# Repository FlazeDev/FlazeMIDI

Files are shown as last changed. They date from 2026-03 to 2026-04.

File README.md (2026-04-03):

# FlazeMIDI

Screenshot (118)

This is a simple 25 key MIDI Controller with 3 rotary encoders. I used a Raspberry Pi Pico as the brain for this MIDI Controller.

## Bill of Materials (BOM)
|BOM for FlazeMIDI|FIELD2 |FIELD3 |FIELD4 |FIELD5 |FIELD6 |
|---|---|---|---|---|---|
|S.No |Name Of Part |Link |Price per item(W/o Shipping)|Quantity |Total Cost Of Item(W/O Shipping)|
|1 |Raspberry pi pico |https://robu.in/product/raspberry-pi-pico-with-headers/ |499.00 INR |1 |499.00 INR |
|2 |1N4148 diodes(pack of 50) |https://www.amazon.in/gp/product/B0B53NV1QC/ref=ox_sc_act_title_1?smid=A3OFZYSBUU01KL&psc=1|99.00 INR |1 |99.00 INR |
|3 |Switches(pack of 10) |https://stackskb.com/store/click-inc-hp-switch-pack-of-10-pre-order/ |180.00 INR |3 |540.00 INR |
|4 |EC11 Rotary Encoders(pack of 5)|https://stackskb.com/store/click-inc-hp-switch-pack-of-10-pre-order/ |696.00 INR |1 |696.00 INR |
|5 |Keycaps(pack of 5) |https://meckeys.com/shop/accessories/keyboard-accessories/keycaps/blank-dsa-keycaps-1u/ |95.00 INR |5 |475.00 INR |
|6 |PCB Fabrication |jlcpcb.com |976.96 INR |1 |976.96 INR |
|7 |PCB Shipping |jlcpcb.com |1,091.73 INR |1 |1,091.73 INR |
|8 |M3x4mm Heatsets |I already have it |0.00 INR |4 |0.00 INR |
|9 |M3x4mm screws |I already have it |0.00 INR |4 |0.00 INR |
| | | | | | |
| | | | | | |
| | | | | | |
| | | | | | |
| | | | | | |
| | | | | | |
| | | | |Total INR(only including  Shipping for pcb)|4,377.69 INR |
| | | | |Total USD |$48.15 |

### Total Project Cost
$48.15 without shipping. Shipping should take another $10 max.
Total Project cost: **$58**

## Schematic & PCB
Screenshot (109)
Screenshot (104)

I made the pcb in kicad

## 3d Case
Screenshot (119)

The case consists of 3 parts, the top cover, bottom cover and a stand that attaches to the bottom. Everything is connected using m3 heat set inserts and screws.
I made the case in onshape. here's the link for the onshape project:- https://cad.onshape.com/documents/0f47473beb05ba1bc00654df/w/e1cbcdd202a0a0f5e24ed7bd/e/dbeb9d6fbd234f685e1c68c6

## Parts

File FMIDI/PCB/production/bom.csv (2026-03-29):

Designator | Footprint | Quantity | Value | LCSC Part #
D1, D10, D11, D12, D13, D14, D15, D16, D17, D18, D19, D2, D20, D21, D22, D23, D24, D25, D3, D4, D5, D6, D7, D8, D9 | D_DO-35_SOD27_P7.62mm_Horizontal | 25 | ~
S1, S10, S11, S12, S13, S14, S15, S16, S17, S18, S19, S2, S20, S21, S22, S23, S24, S25, S3, S4, S5, S6, S7, S8, S9 | MX_PCB_1.00u | 25 | ~
SW1, SW2, SW3 | Encoder_EC11_MX | 3 | RotaryEncoder_Switch
U1 | Raspberry_Pi_Pico | 1 | Raspberry_Pi_Pico

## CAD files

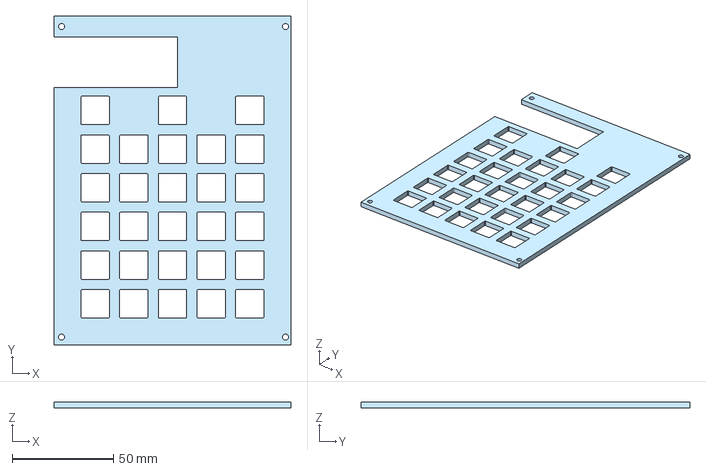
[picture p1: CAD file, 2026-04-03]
FMIDI/CAD/FMIDI_Top.step
116.8 x 162.0 x 3.00 mm

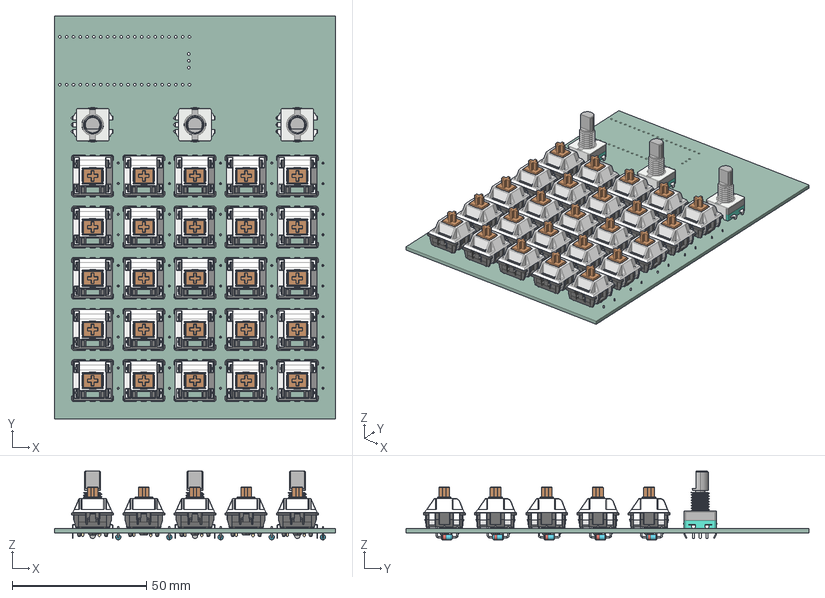
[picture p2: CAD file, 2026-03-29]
FMIDI/PCB/MIDI/MIDI.step
104.8 x 150.0 x 25.6 mm
ѽת±ძǷ x 3
SW_Cherry_MX_PCB_cp x 25
D_DO-35_SOD27_P7.62mm_Horizontal x 25
_autosave-MIDI_PCB

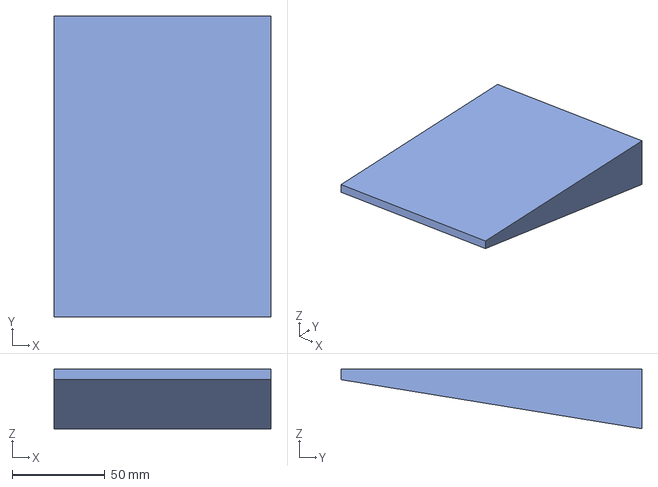
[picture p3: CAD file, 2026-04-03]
FMIDI/CAD/FMIDI_Stand.step
116.8 x 162.0 x 32.0 mm

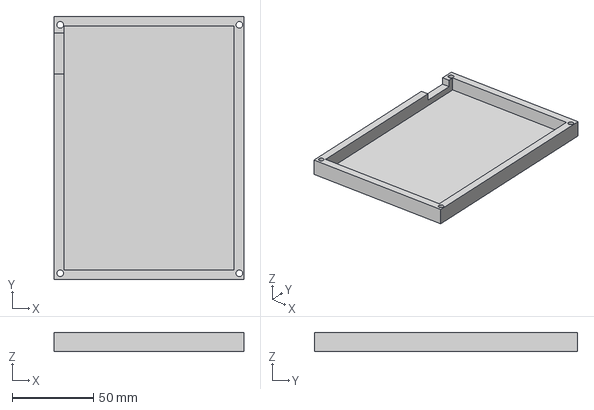
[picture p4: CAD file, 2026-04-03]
FMIDI/CAD/FMIDI_Bottom.step
116.8 x 162.0 x 12.0 mm

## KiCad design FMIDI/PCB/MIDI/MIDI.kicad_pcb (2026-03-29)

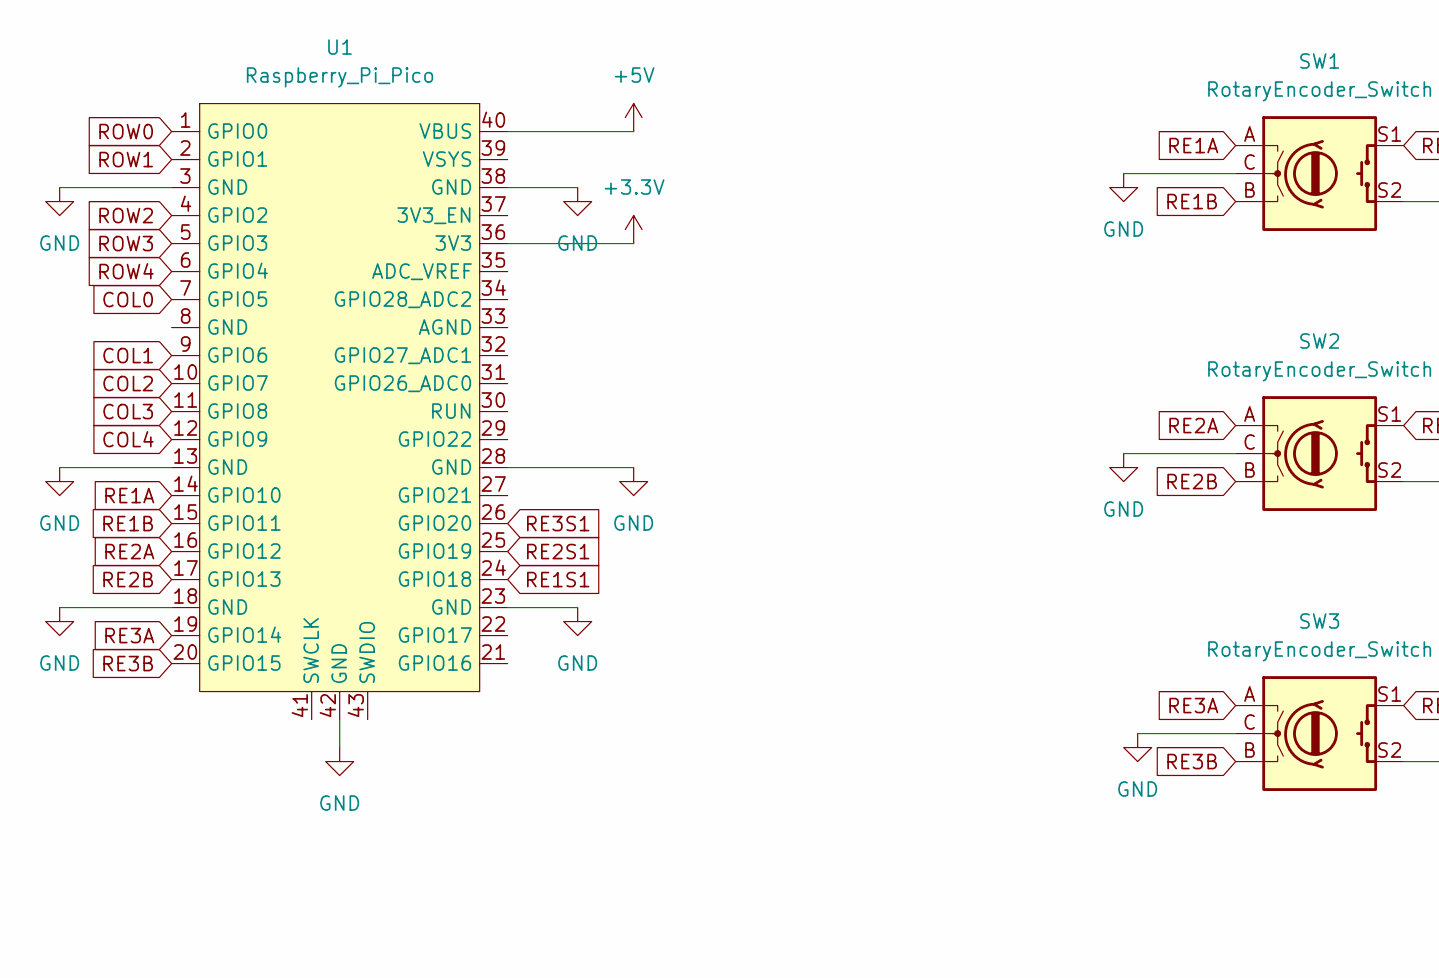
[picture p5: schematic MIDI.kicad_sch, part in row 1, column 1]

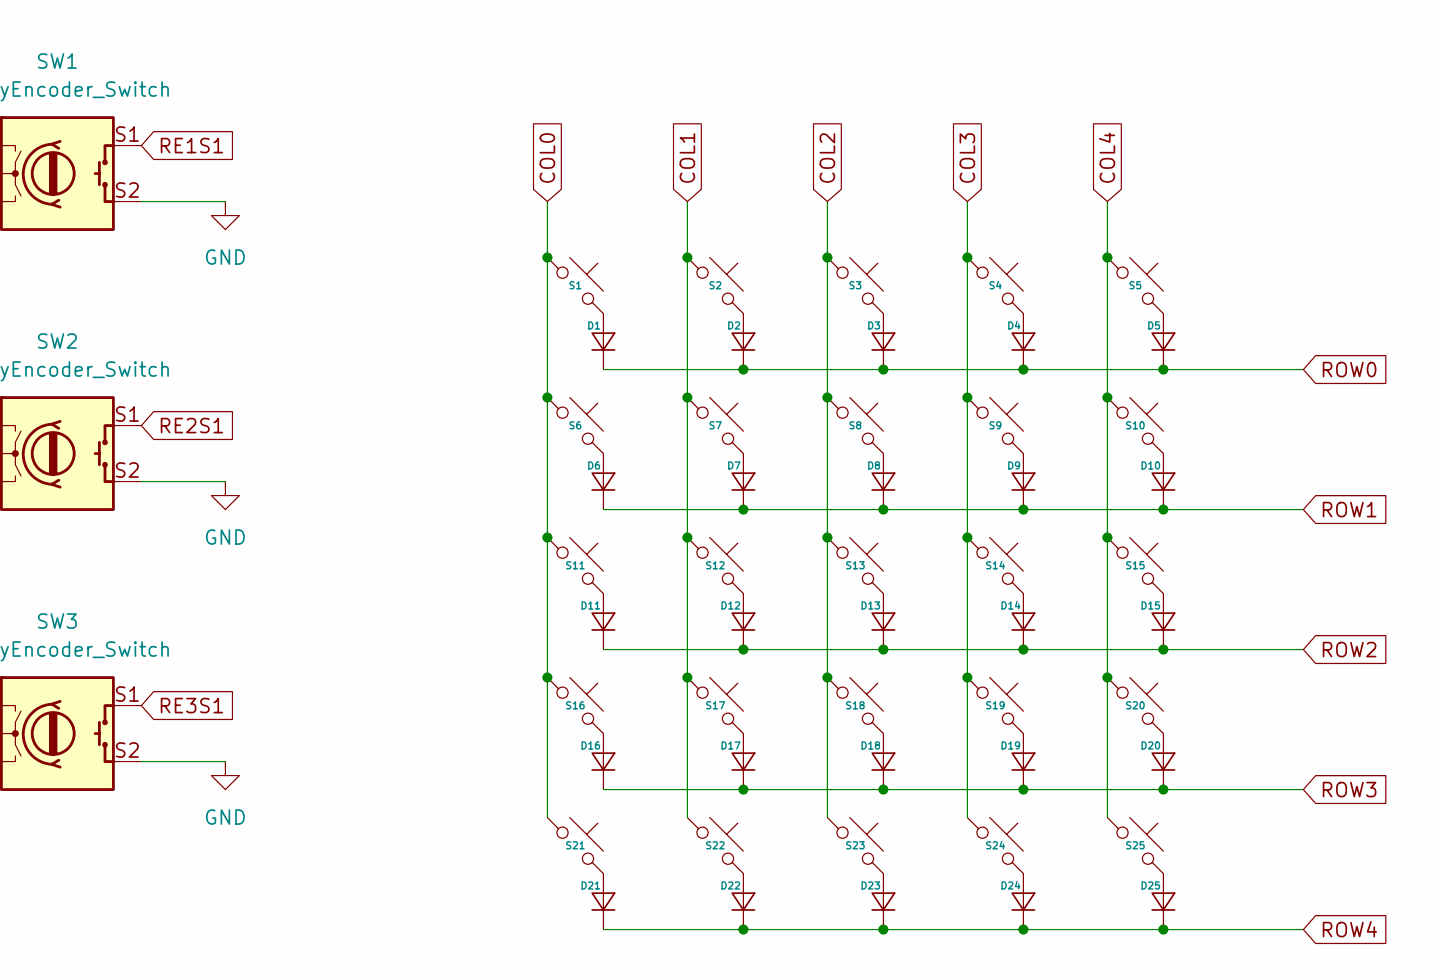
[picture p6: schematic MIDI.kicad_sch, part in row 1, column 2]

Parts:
D1, D2, D3, D4, D5, D6, D7, D8, D9, D10, D11, D12, D13, D14, D15, D16, D17, D18, D19, D20, D21, D22, D23, D24, D25: D_DO-35_SOD27_P7.62mm_Horizontal
S1, S2, S3, S4, S5, S6, S7, S8, S9, S10, S11, S12, S13, S14, S15, S16, S17, S18, S19, S20, S21, S22, S23, S24, S25: MX_PCB_1.00u
SW1, SW2, SW3: RotaryEncoder_Switch; Encoder_EC11_MX
U1: Raspberry_Pi_Pico

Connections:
+3.3V: U1.36 (3V3)
+5V: U1.40 (VBUS)
COL0: S1.1, S6.1, S11.1, S16.1, S21.1, U1.7 (GPIO5)
COL1: S2.1, S7.1, S12.1, S17.1, S22.1, U1.9 (GPIO6)
COL2: S3.1, S8.1, S13.1, S18.1, S23.1, U1.10 (GPIO7)
COL3: S4.1, S9.1, S14.1, S19.1, S24.1, U1.11 (GPIO8)
COL4: S5.1, S10.1, S15.1, S20.1, S25.1, U1.12 (GPIO9)
GND: SW1.C, SW1.S2, SW2.C, SW2.S2, SW3.C, SW3.S2, U1.3 (GND), U1.13 (GND), U1.18 (GND), U1.23 (GND), U1.28 (GND), U1.38 (GND), U1.42 (GND)
unnamed: D1.2 (A), S1.2
unnamed: D2.2 (A), S2.2
unnamed: D3.2 (A), S3.2
unnamed: D4.2 (A), S4.2
unnamed: D5.2 (A), S5.2
unnamed: D6.2 (A), S6.2
unnamed: D7.2 (A), S7.2
unnamed: D8.2 (A), S8.2
unnamed: D9.2 (A), S9.2
unnamed: D10.2 (A), S10.2
unnamed: D11.2 (A), S11.2
unnamed: D12.2 (A), S12.2
unnamed: D13.2 (A), S13.2
unnamed: D14.2 (A), S14.2
unnamed: D15.2 (A), S15.2
unnamed: D16.2 (A), S16.2
unnamed: D17.2 (A), S17.2
unnamed: D18.2 (A), S18.2
unnamed: D19.2 (A), S19.2
unnamed: D20.2 (A), S20.2
unnamed: D21.2 (A), S21.2
unnamed: D22.2 (A), S22.2
unnamed: D23.2 (A), S23.2
unnamed: D24.2 (A), S24.2
unnamed: D25.2 (A), S25.2
RE1A: SW1.A, U1.14 (GPIO10)
RE1B: SW1.B, U1.15 (GPIO11)
RE1S1: SW1.S1, U1.24 (GPIO18)
RE2A: SW2.A, U1.16 (GPIO12)
RE2B: SW2.B, U1.17 (GPIO13)
RE2S1: SW2.S1, U1.25 (GPIO19)
RE3A: SW3.A, U1.19 (GPIO14)
RE3B: SW3.B, U1.20 (GPIO15)
RE3S1: SW3.S1, U1.26 (GPIO20)
ROW0: D1.1 (K), D2.1 (K), D3.1 (K), D4.1 (K), D5.1 (K), U1.1 (GPIO0)
ROW1: D6.1 (K), D7.1 (K), D8.1 (K), D9.1 (K), D10.1 (K), U1.2 (GPIO1)
ROW2: D11.1 (K), D12.1 (K), D13.1 (K), D14.1 (K), D15.1 (K), U1.4 (GPIO2)
ROW3: D16.1 (K), D17.1 (K), D18.1 (K), D19.1 (K), D20.1 (K), U1.5 (GPIO3)
ROW4: D21.1 (K), D22.1 (K), D23.1 (K), D24.1 (K), D25.1 (K), U1.6 (GPIO4)

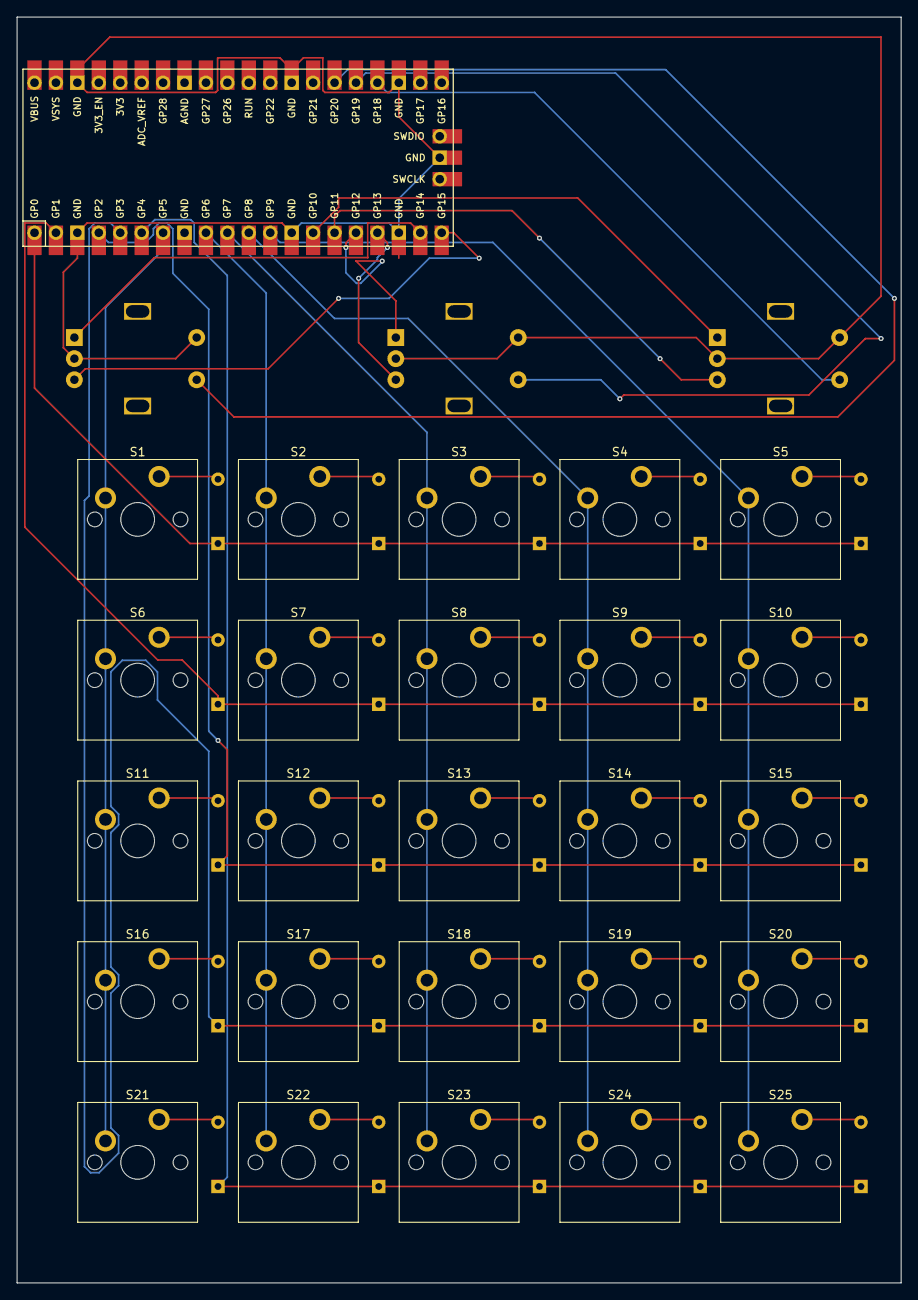
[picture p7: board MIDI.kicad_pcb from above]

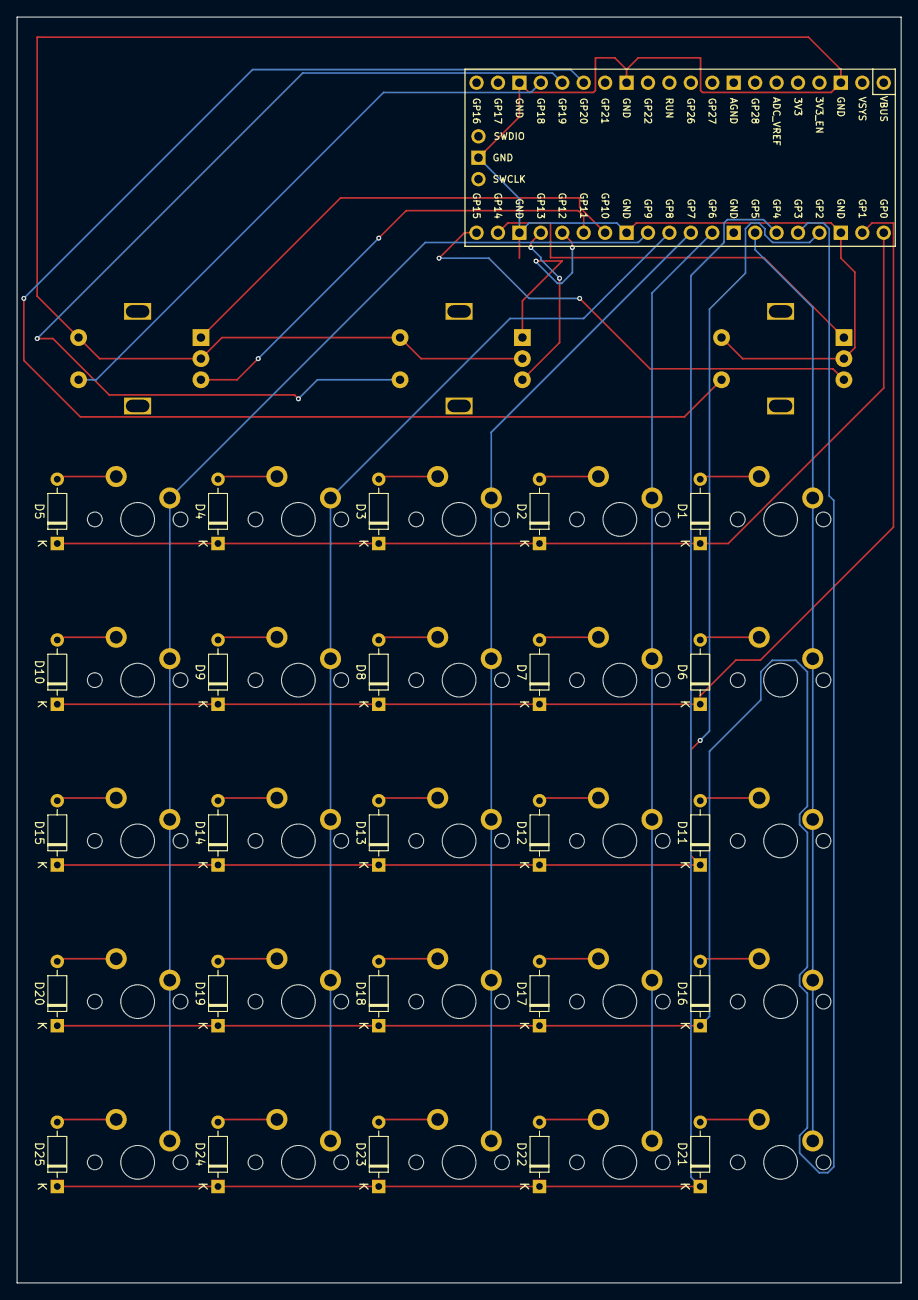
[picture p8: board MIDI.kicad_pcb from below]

Board: 2 copper layers, 104.8 x 150.0 mm, 54 parts (25 on the bottom side), 45 nets.

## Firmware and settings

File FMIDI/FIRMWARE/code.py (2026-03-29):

import board
import digitalio
import rotaryio
import usb_midi
import time
import adafruit_midi
from adafruit_midi.note_on import NoteOn
from adafruit_midi.note_off import NoteOff
from adafruit_midi.control_change import ControlChange

# ---------------- MIDI ----------------
midi = adafruit_midi.MIDI(midi_out=usb_midi.ports, out_channel=0)

# ---------------- MX MATRIX PINS (5x5) ----------------
# 5 Rows and 5 Columns for 25 keys
ROWS = [board.GP2, board.GP3, board.GP4, board.GP5, board.GP6]
COLS = [board.GP7, board.GP8, board.GP9, board.GP10, board.GP11]

row_pins = []
for r in ROWS:
    pin = digitalio.DigitalInOut(r)
    pin.direction = digitalio.Direction.OUTPUT
    pin.value = True
    row_pins.append(pin)

col_pins = []
for c in COLS:
    pin = digitalio.DigitalInOut(c)
    pin.direction = digitalio.Direction.INPUT
    pin.pull = digitalio.Pull.UP
    col_pins.append(pin)

# State tracking for 25 keys
pressed = [[False]*5 for _ in range(5)]

# ---------------- NOTE MAP (C2 to C4) ----------------
NOTES = [i for i in range(36, 61)]

# ---------------- ENCODERS & SWITCHES ----------------
encs = [
    rotaryio.IncrementalEncoder(board.GP12, board.GP13),
    rotaryio.IncrementalEncoder(board.GP14, board.GP15),
    rotaryio.IncrementalEncoder(board.GP16, board.GP17)
]

# Encoder internal switches
sw_pins = [board.GP18, board.GP19, board.GP20]
switches = []
for p in sw_pins:
    sw = digitalio.DigitalInOut(p)
    sw.direction = digitalio.Direction.INPUT
    sw.pull = digitalio.Pull.UP
    switches.append(sw)

last_enc_pos = [e.position for e in encs]
last_sw_state = [True, True, True]

# ---------------- SCANNING FUNCTIONS ----------------

def scan_matrix():
    for r in range(5):
        row_pins[r].value = False  # Set current row to Ground
        for c in range(5):
            # Check if MX Switch is closed
            if not col_pins[c].value:
                if not pressed[r][c]:
                    note = NOTES[r * 5 + c]
                    midi.send(NoteOn(note, 100))
                    pressed[r][c] = True
            else:
                if pressed[r][c]:
                    note = NOTES[r * 5 + c]
                    midi.send(NoteOff(note, 0))
                    pressed[r][c] = False
        row_pins[r].value = True  # Reset row to High

def read_reaper_controls():
    global last_enc_pos, last_sw_state
    
    for i in range(3):
        # 1. Encoders: Relative Mode (Reaper 'Relative 1')
        curr_pos = encs[i].position
        if curr_pos != last_enc_pos[i]:
            # Send 65 for turn-right, 63 for turn-left
            val = 65 if curr_pos > last_enc_pos[i] else 63
            midi.send(ControlChange(20 + i, val))
            last_enc_pos[i] = curr_pos

        # 2. Switches: Momentary CC
        curr_sw = switches[i].value
        if curr_sw != last_sw_state[i]:
            val = 127 if not curr_sw else 0
            midi.send(ControlChange(30 + i, val))
            last_sw_state[i] = curr_sw

# ---------------- MAIN LOOP ----------------
while True:
    scan_matrix()
    read_reaper_controls()
    # A tiny sleep helps debounce physical MX switch contacts
    time.sleep(0.005)
